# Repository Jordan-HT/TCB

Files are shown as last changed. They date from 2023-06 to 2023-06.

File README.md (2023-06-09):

# Thyristor Control Board (TCB) Project
By Jordan Harris-Toovy for internal and shared projects.
This repo contains the design files and accocated C/c++ code for a custom RP2040-powered dual thyristor control module. It is intended to be used to drive either two large SCRs as part of a SCR bridge rectifier, or a single large TriAC as the code of a larger power supply. Via an onboard current sensor, current measurements can be used in a feedback system if desired. Additionally, the I/O on the low-voltage side of the isolation barrier will allow for CNC integration for novel applications.

Currently, the board is in production of the first test batch, with an estimated arrival date of 2023-06-16. Code for the onboard Seeed XIAO RP2040 is also being developed, however, it is not yet ready. I will update this repo with the code and documentation as it is developed.

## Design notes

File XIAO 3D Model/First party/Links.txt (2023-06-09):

https://wiki.seeedstudio.com/XIAO-RP2040-with-Arduino/

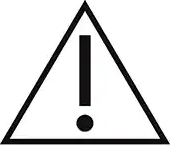
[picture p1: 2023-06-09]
Symbols/Caution.png

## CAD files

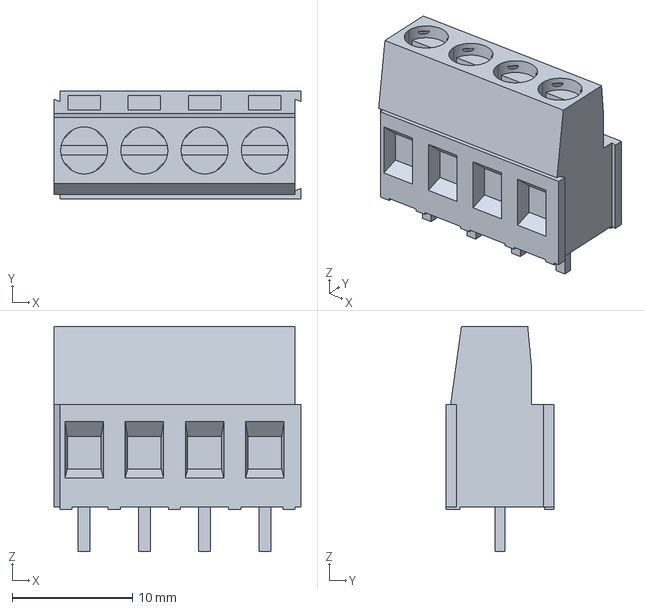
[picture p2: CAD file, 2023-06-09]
Imported Parts/796682-4/c-796682-4-b-3d.stp
20.5 x 9.00 x 18.7 mm

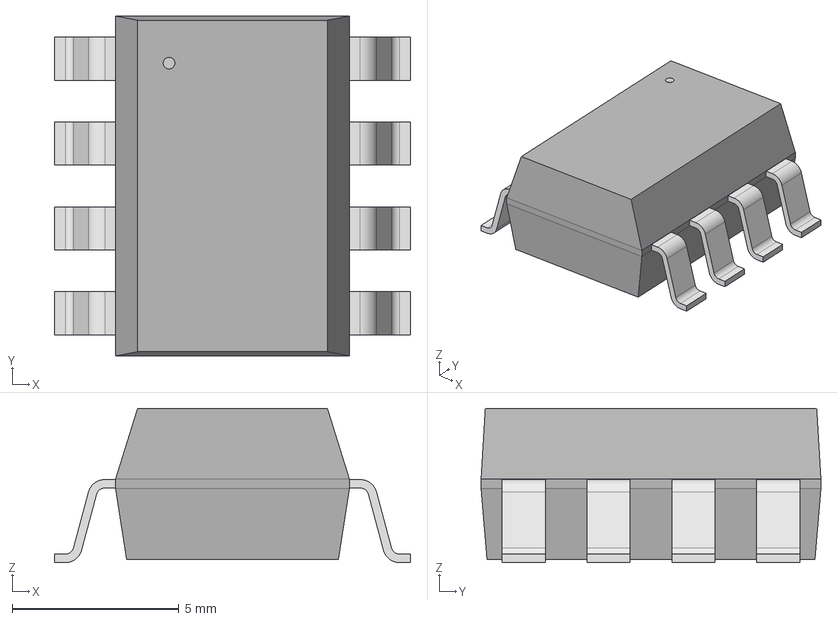
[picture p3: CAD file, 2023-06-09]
Imported Parts/ACPL-827-300E/ACPL-827-300E_BRA.step
10.7 x 10.2 x 4.62 mm

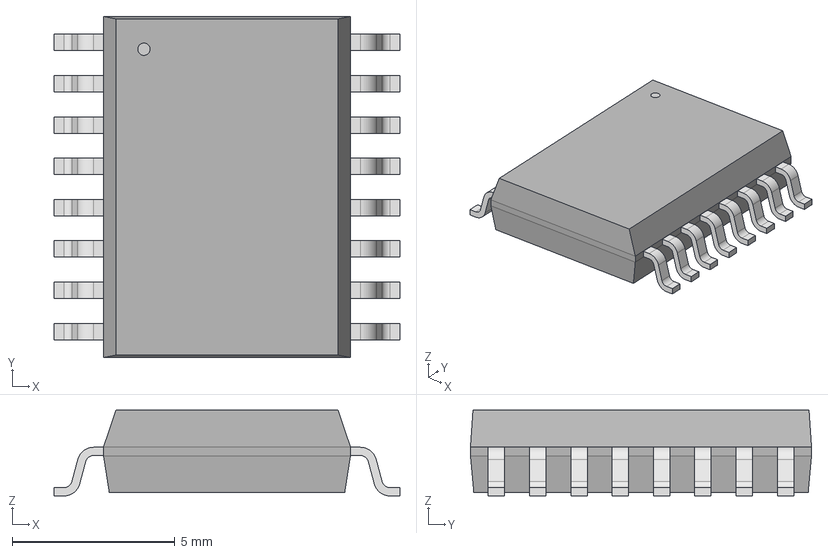
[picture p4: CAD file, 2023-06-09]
Imported Parts/ACS720KLATR-35AB-T/SOICW16_LA_ALM.step
10.6 x 10.5 x 2.64 mm

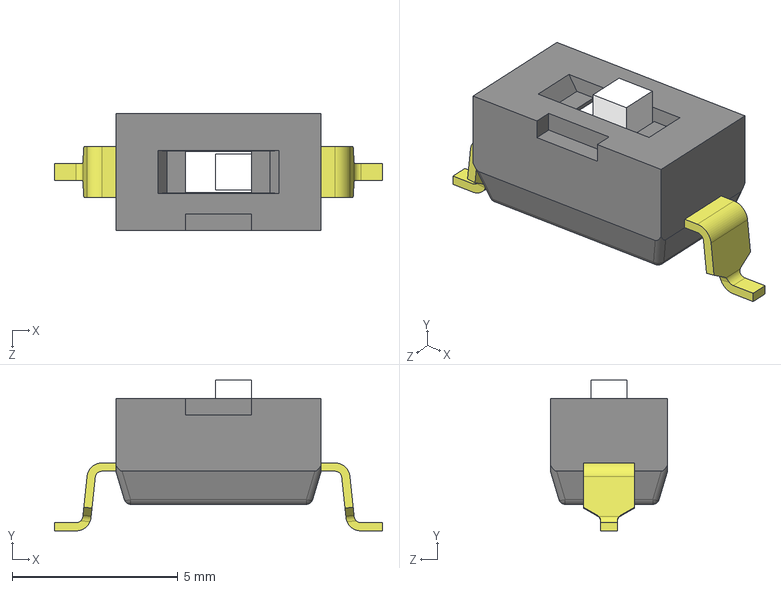
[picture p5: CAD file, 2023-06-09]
Imported Parts/DS04-254-1-01BK-SMT/CUI_DEVICES_DS04-254-1-01BK-SMT.step
9.90 x 4.55 x 3.54 mm

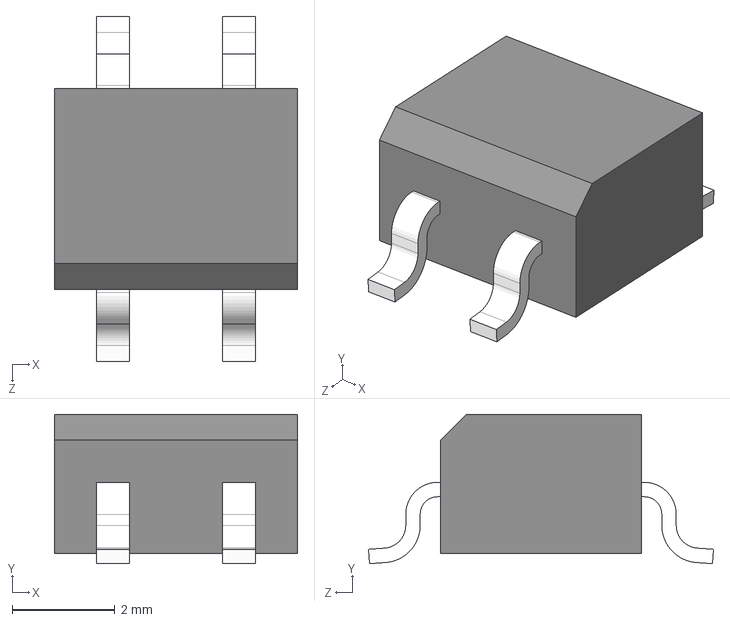
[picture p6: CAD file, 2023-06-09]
Imported Parts/MB10S-13/MB10S-13.STEP
4.72 x 2.90 x 6.70 mm

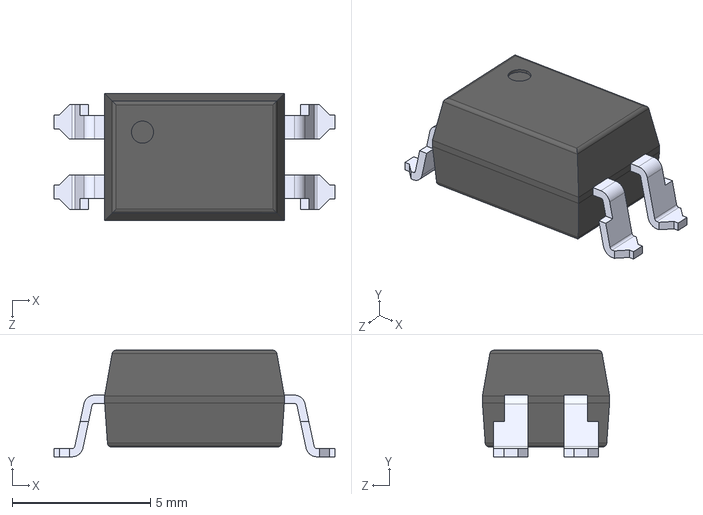
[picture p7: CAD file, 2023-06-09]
Imported Parts/VOT8121AB-T2/VOT8121AB-T2.step
10.2 x 3.85 x 4.60 mm

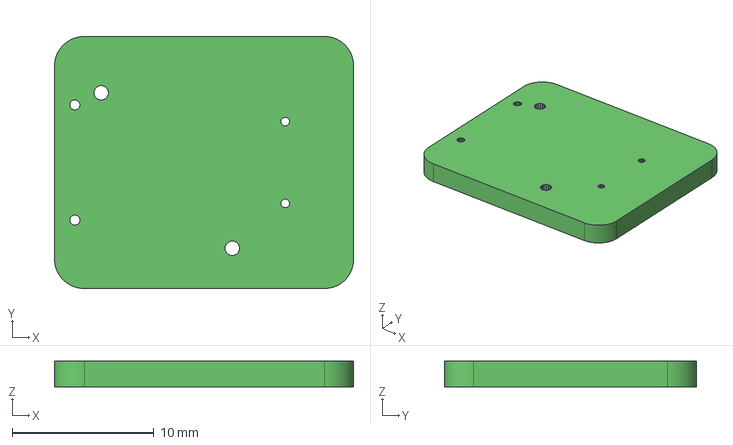
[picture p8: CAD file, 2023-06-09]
XIAO 3D Model/First party/XIAO RP2040 v1.22.step
21.1 x 17.8 x 1.82 mm

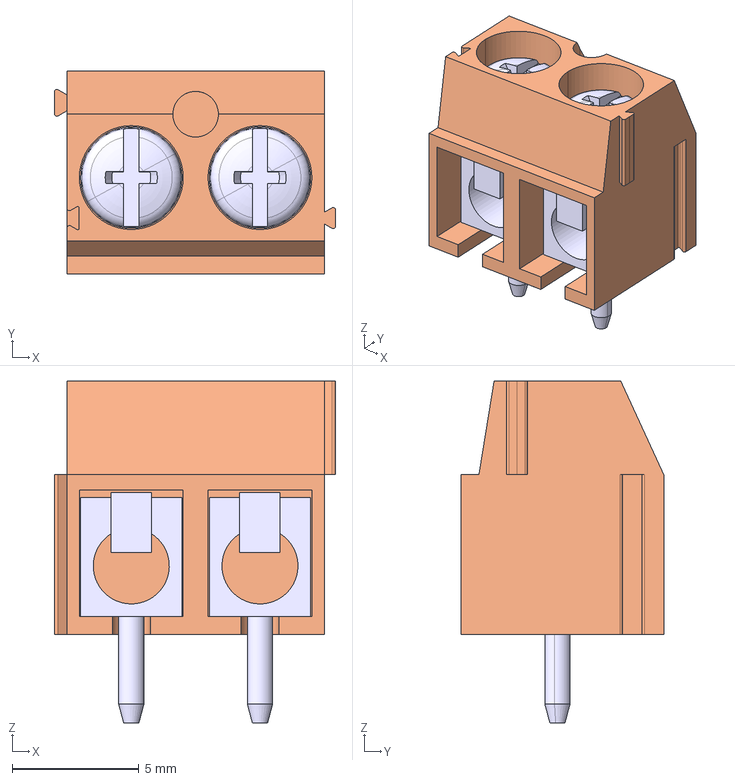
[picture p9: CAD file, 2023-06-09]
Imported Parts/1760490000/1760490000.stp
11.1 x 8.00 x 13.5 mm

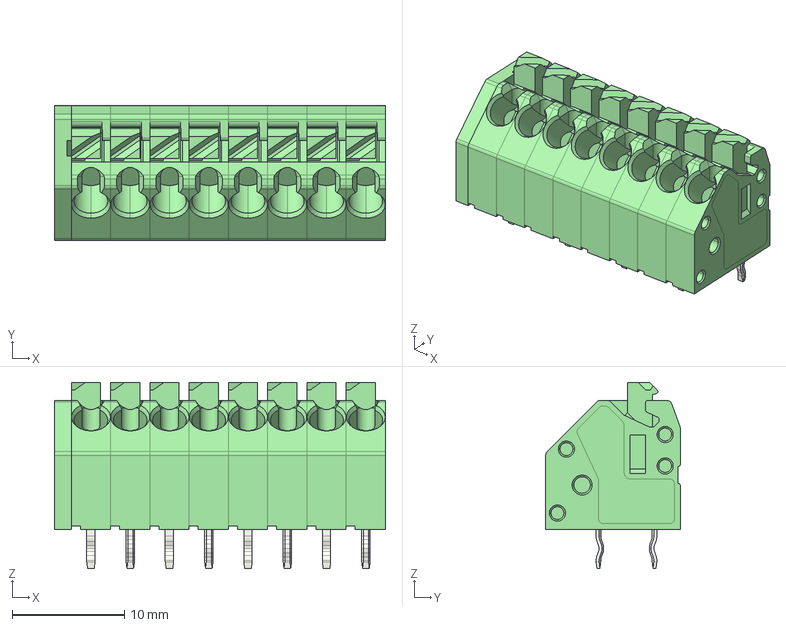
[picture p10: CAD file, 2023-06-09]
Imported Parts/1985250/1985250.stp
29.5 x 12.0 x 16.6 mm

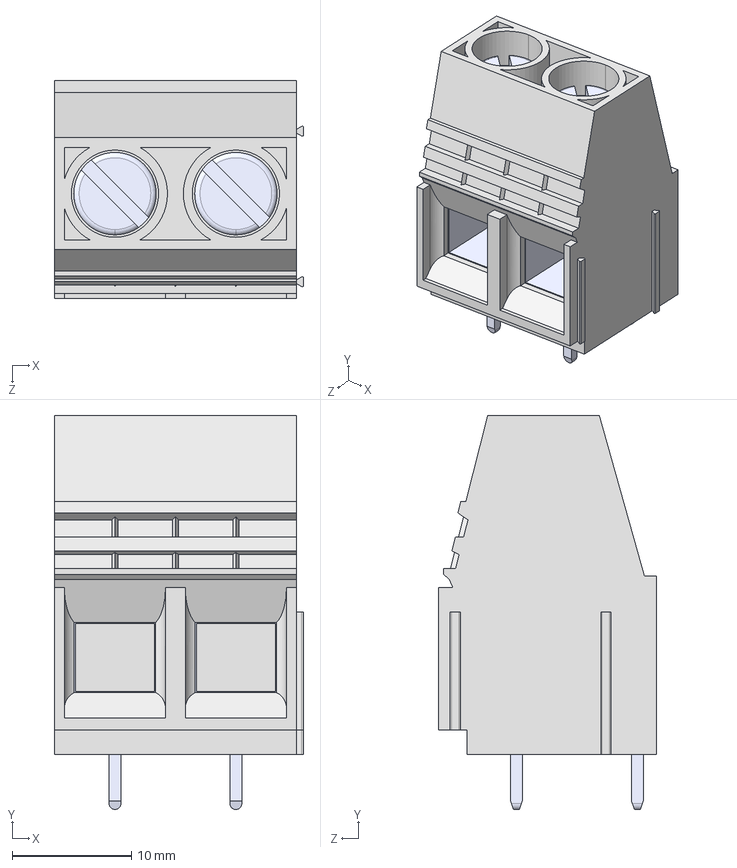
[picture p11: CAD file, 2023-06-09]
Imported Parts/VP0265840000G/VP0265840000G--3DModel-STEP-269445.STEP
20.9 x 33.1 x 18.3 mm

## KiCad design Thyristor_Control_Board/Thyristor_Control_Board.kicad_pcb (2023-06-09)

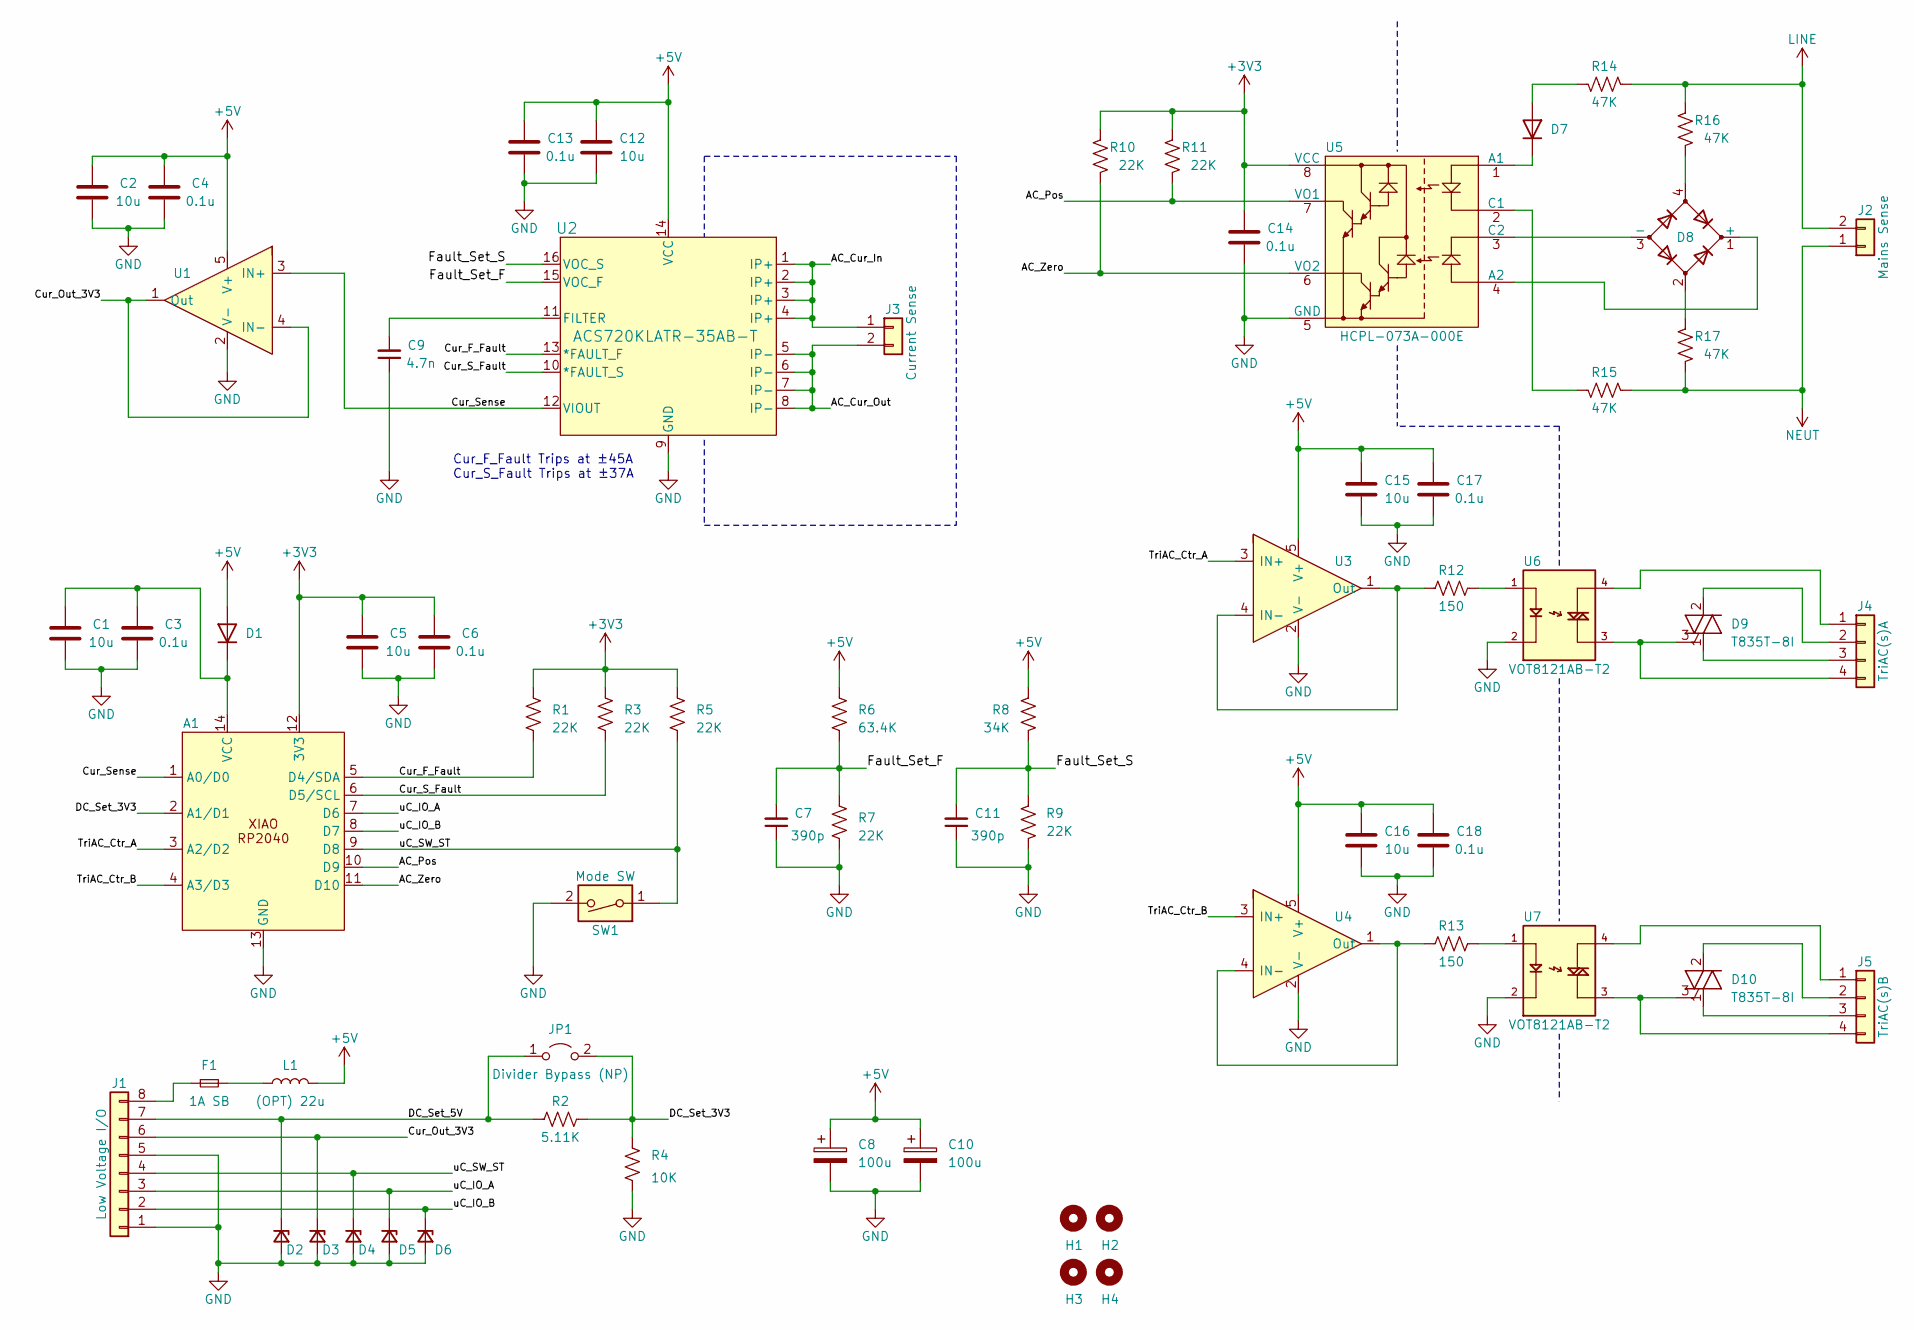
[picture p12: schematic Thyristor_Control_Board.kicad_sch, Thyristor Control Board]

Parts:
A1: N/A; seeed_studio_XIAO_RP2040; Part Number 1597-102010428-ND
C1, C2, C5, C12, C15, C16: 10u; C_0805_2012Metric; Part Number CL21B106KOQNNNE
C3, C4, C6, C13, C14, C17, C18: 0.1u; C_0805_2012Metric; Part Number CL21B104KBCNNNC
C7, C11: 390p; C_0805_2012Metric; Part Number C0805C391J5GAC7800
C8, C10: 100u; CP_Radial_D6.3mm_P2.50mm; Part Number A750EK107M1CAAE018
C9: 4.7n; C_0603_1608Metric; Part Number C0603C472K5HAC7867
D1: SS14-LTP; DO-214AC; Part Number SS14-LTP
D2, D3, D4, D5, D6: ESD9X7.0ST5G; D_SOD-923; Part Number ESD9X7.0ST5G
D7: S1M; D_SMA; Part Number S1M
D8: MB10S-13; 4-BESOP; Part Number MB10S-13
D9, D10: T835T-8I; TO-220-3_Vertical; Part Number T835T-8I
F1: 1A SB; Fuse_1206_3216Metric; Part Number 0685T1000-01
H1, H2, H3, H4: MountingHole; MountingHole_2.7mm_M2.5_ISO14580; Part Number NA; Digikey Link NA
J1: Low Voltage I/O; CONN_1985250_PXC; Part Number 1985250
J2: Mains Sense; CONN2_1760490000_WED; Part Number 1760490000
J3: Current Sense; CONN04_VP026584_20P32X18P3_AMP; Part Number VP0265840000G
J4: TriAC(s)A; CONN4_796682-4_TEC; Part Number 796682-4
J5: TriAC(s)B; CONN4_796682-4_TEC; Part Number 796682-4
JP1: Divider Bypass (NP); R_1206_3216Metric_Pad1.30x1.75mm_HandSolder; Part Number RMCF0805ZT0R00
L1: (OPT) 22u; L_Axial_L7.0mm_D3.3mm_P10.16mm_Horizontal_Fastron_MICC; Part Number B78108E1223K009
R1, R3, R5, R7, R9, R10, R11: 22K; R_0805_2012Metric; Part Number RC0805FR-0722KL
R2: 5.11K; R_0805_2012Metric; Part Number RK73H2ATTD5111F
R4: 10K; R_0805_2012Metric; Part Number RK73H2ATTD1002F
R6: 63.4K; R_0805_2012Metric; Part Number RC0805FR-0763K4L
R8: 34K; R_0805_2012Metric; Part Number RC0805FR-0734KL
R12, R13: 150; R_0805_2012Metric; Part Number RC0805FR-07150RL
R14, R15, R16, R17: 47K; R_Axial_DIN0516_L15.5mm_D5.0mm_P20.32mm_Horizontal; Part Number RR03J47KTB
SW1: Mode SW; SW_DS04-254-1-01BK-SMT; Part Number DS04-254-1-01BK-SMT
U1, U3, U4: TLV9301IDBVR; SOT-23-5; Part Number TLV9301IDBVR
U2: ACS720KLATR-35AB-T; 16SOICW-LA; Part Number ACS720KLATR-35AB-T
U5: HCPL-073A-000E; 8-SOIC_3.9mm_Broadcom; Part Number HCPL-073A-000E
U6, U7: VOT8121AB-T2; SOIC254P1016X440-4N; Part Number VOT8121AB-T2

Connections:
+3V3: A1.12 (3V3), C5.2, C6.2, C14.2, R1.1, R3.1, R5.1, R10.1, R11.1, U5.8 (VCC)
+5V: C2.2, C4.2, C8.1, C10.1, C12.2, C13.2, C15.2, C16.2, C17.2, C18.2, D1.2 (A), L1.2, R6.1, R8.1, U1.5 (V+), U2.14 (VCC), U3.5 (V+), U4.5 (V+)
/AC_Cur_In: J3.1, U2.1 (IP+), U2.2 (IP+), U2.3 (IP+), U2.4 (IP+)
/AC_Cur_Out: J3.2, U2.5 (IP-), U2.6 (IP-), U2.7 (IP-), U2.8 (IP-)
/AC_Pos: A1.10 (D9), R11.2, U5.7 (VO1)
/AC_Zero: A1.11 (D10), R10.2, U5.6 (VO2)
/Cur_F_Fault: A1.5 (D4/SDA), R1.2, U2.13 (*FAULT_F)
/Cur_Out_3V3: D3.1 (K), J1.6, U1.1 (Out), U1.4 (IN-)
/Cur_S_Fault: A1.6 (D5/SCL), R3.2, U2.10 (*FAULT_S)
/Cur_Sense: A1.1 (A0/D0), U1.3 (IN+), U2.12 (VIOUT)
/DC_Set_3V3: A1.2 (A1/D1), JP1.2 (B), R2.1, R4.1
/DC_Set_5V: D2.1 (K), J1.7, JP1.1 (A), R2.2
/Fault_Set_F: C7.2, R6.2, R7.1, U2.15 (VOC_F)
/Fault_Set_S: C11.2, R8.2, R9.1, U2.16 (VOC_S)
/TriAC_Ctr_A: A1.3 (A2/D2), U3.3 (IN+)
/TriAC_Ctr_B: A1.4 (A3/D3), U4.3 (IN+)
/uC_IO_A: A1.7 (D6), D5.1 (K), J1.3
/uC_IO_B: A1.8 (D7), D6.1 (K), J1.2
/uC_SW_ST: A1.9 (D8), D4.1 (K), J1.4, R5.2, SW1.1
GND: A1.13 (GND), C1.1, C2.1, C3.1, C4.1, C5.1, C6.1, C7.1, C8.2, C9.1, C10.2, C11.1, C12.1, C13.1, C14.1, C15.1, C16.1, C17.1, C18.1, D2.2 (A), D3.2 (A), D4.2 (A), D5.2 (A), D6.2 (A), J1.1, J1.5, R4.2, R7.2, R9.2, SW1.2, U1.2 (V-), U2.9 (GND), U3.2 (V-), U4.2 (V-), U5.5 (GND), U6.2, U7.2
LINE: J2.2, R14.1, R16.1
NEUT: J2.1, R15.1, R17.2
unnamed: A1.14 (VCC), C1.2, C3.2, D1.1 (K)
unnamed: D7.2 (A), R14.2
unnamed: D7.1 (K), U5.1 (A1)
unnamed: D8.1 (+), U5.4 (A2)
unnamed: D8.3 (-), U5.3 (C2)
unnamed: D8.2, R17.1
unnamed: D8.4, R16.2
unnamed: D9.1 (A1), J4.3
unnamed: D9.2 (A2), J4.2
unnamed: D9.3 (G), J4.4, U6.3
unnamed: D10.1 (A1), J5.3
unnamed: D10.2 (A2), J5.2
unnamed: D10.3 (G), J5.4, U7.3
unnamed: F1.2, L1.1
unnamed: F1.1, J1.8
unnamed: J4.1, U6.4
unnamed: J5.1, U7.4
unnamed: R12.2, U6.1
unnamed: R13.2, U7.1
unnamed: C9.2, U2.11 (FILTER)
unnamed: R12.1, U3.1 (Out), U3.4 (IN-)
unnamed: R13.1, U4.1 (Out), U4.4 (IN-)
unnamed: R15.2, U5.2 (C1)

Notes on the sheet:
Cur_F_Fault Trips at ±45A Cur_S_Fault Trips at ±37A

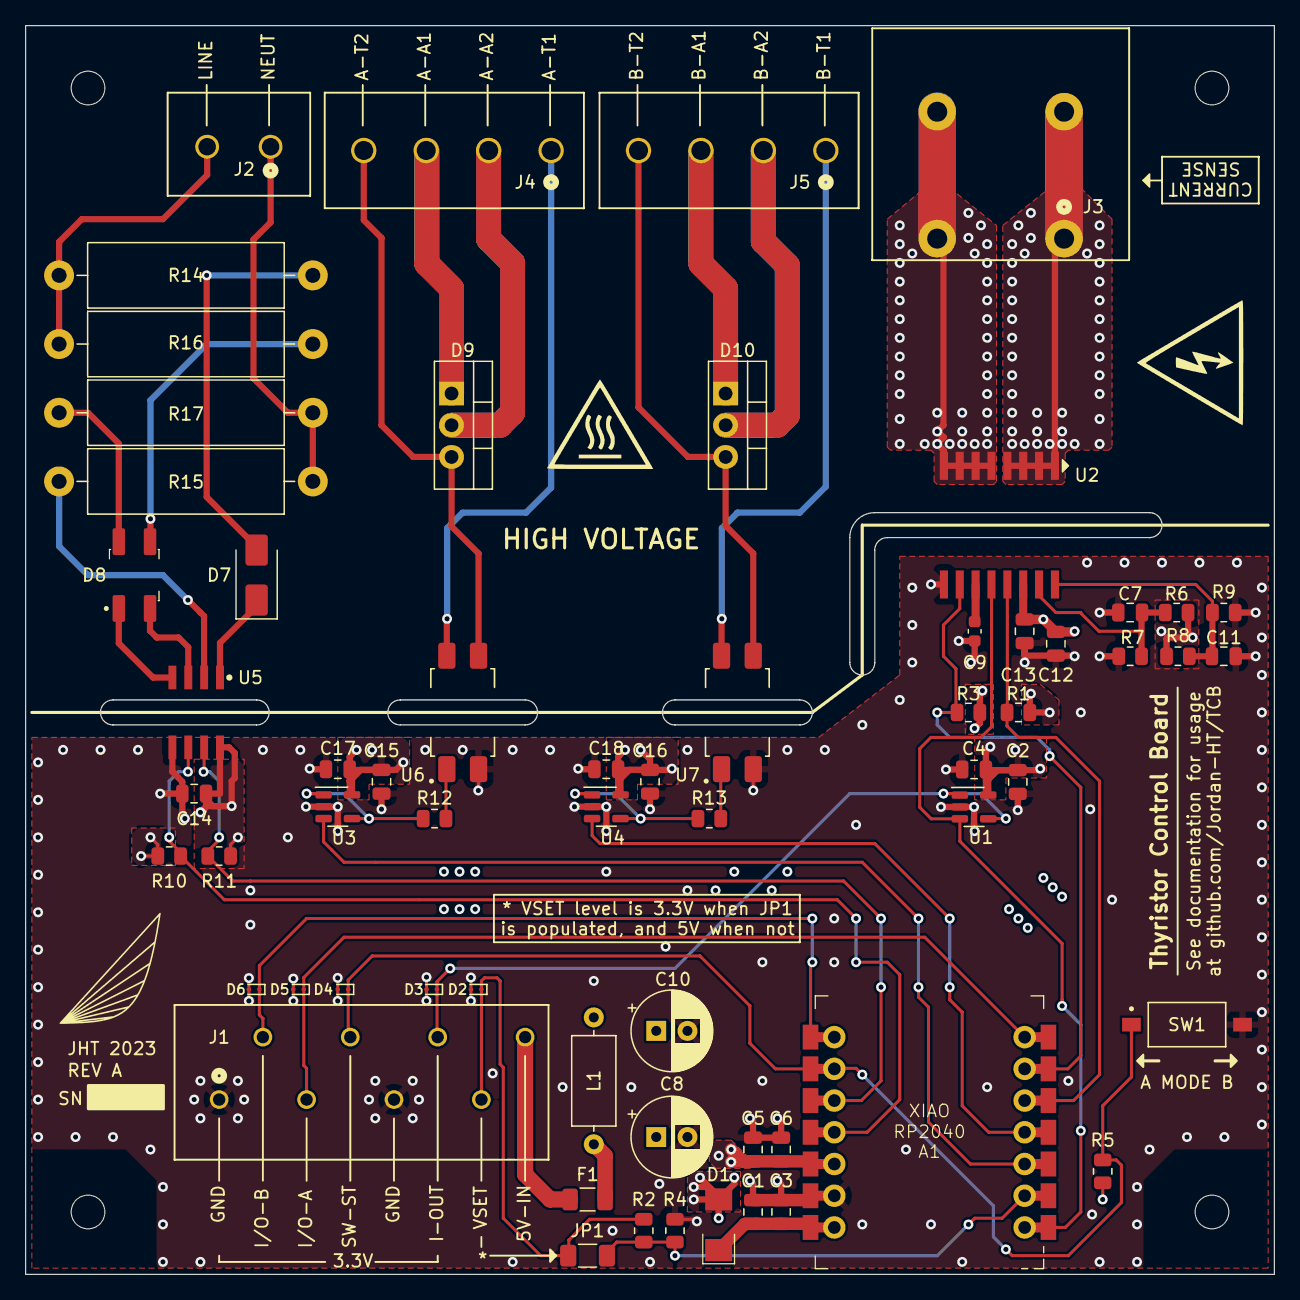
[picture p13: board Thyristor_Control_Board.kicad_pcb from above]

Board: 4 copper layers, 100.0 x 100.0 mm, 66 parts (0 on the bottom side), 45 nets.

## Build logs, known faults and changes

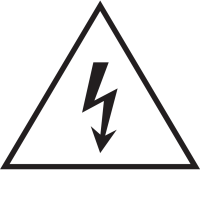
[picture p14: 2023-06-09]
Symbols/Shock_Hazard.png

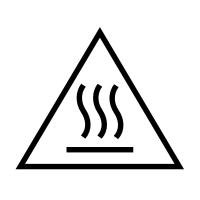
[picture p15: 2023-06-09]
Symbols/Heat_Hazard.png
